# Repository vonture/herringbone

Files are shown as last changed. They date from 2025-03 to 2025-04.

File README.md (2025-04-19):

Herringbone
===============

A split ortholinear grid keyboard made with through hole components.

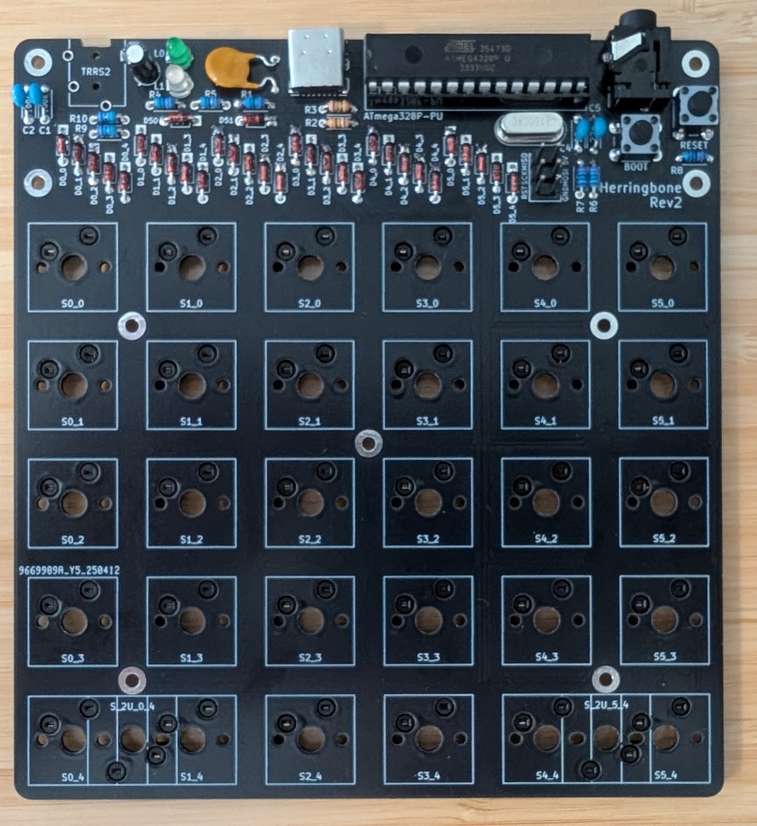
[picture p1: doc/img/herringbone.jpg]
herringbone


## Inspired by
 - [Plaid](https://github.com/hsgw/plaid)
 - [Torn](https://github.com/rtitmuss/torn)
 - [Discipline](https://github.com/coseyfannitutti/discipline)

## BOM

https://octopart.com/bom-tool/v2/9F35A43C-BB16-4669-B263-24A030B88F93

## License



The Herringbone Keyboard is licensed under [Creative Commons Attribution-NonCommercial 4.0 International License](https://creativecommons.org/licenses/by-nc/4.0).

This PCB design may be freely reproduced, modified, and manufactured for personal use only.

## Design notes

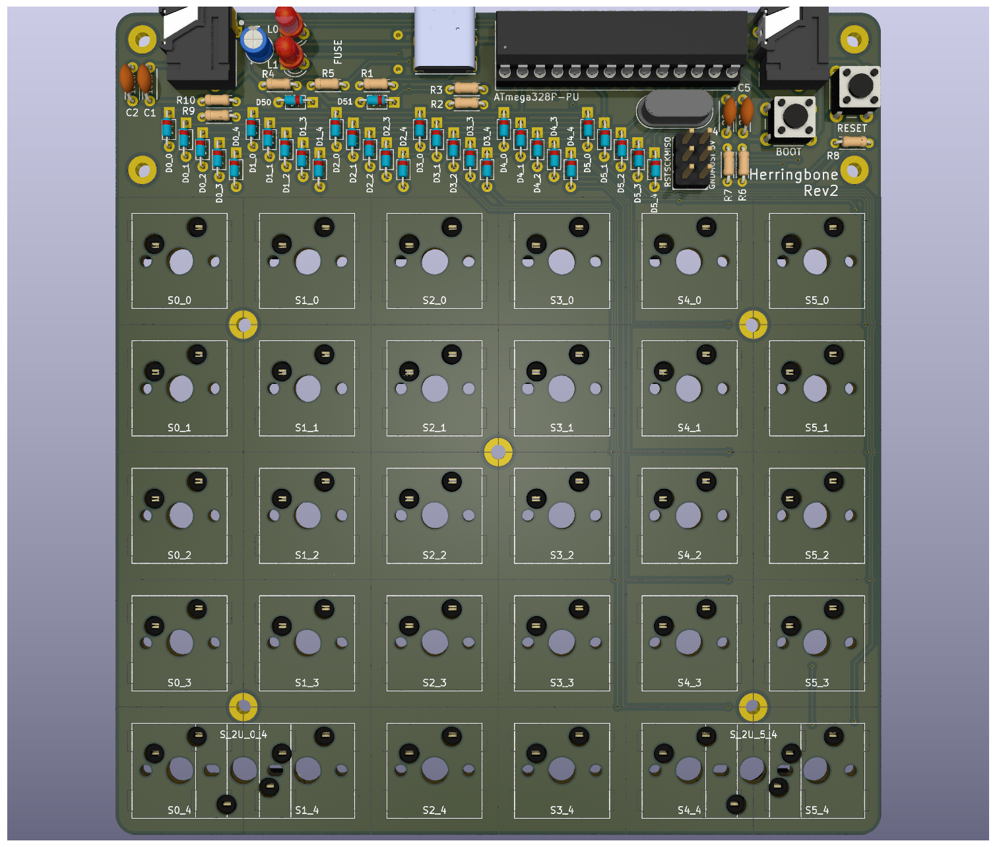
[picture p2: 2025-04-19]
doc/img/pcb.png

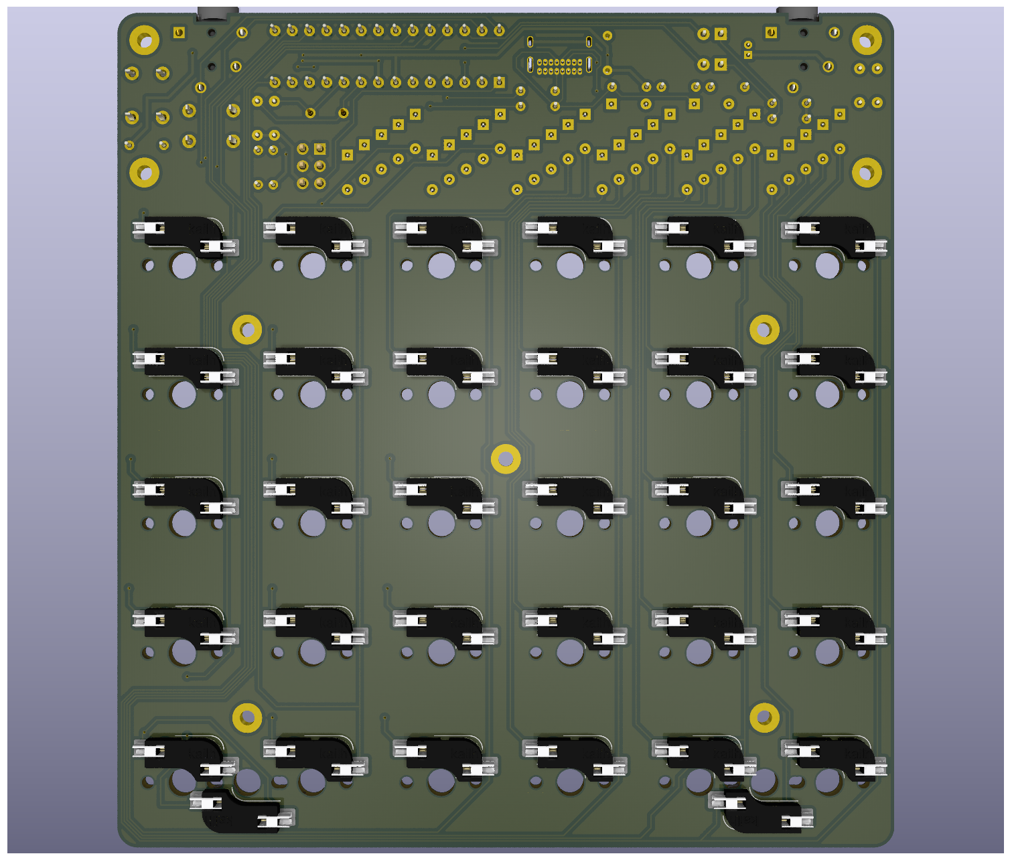
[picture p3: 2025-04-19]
doc/img/pcb_back.png

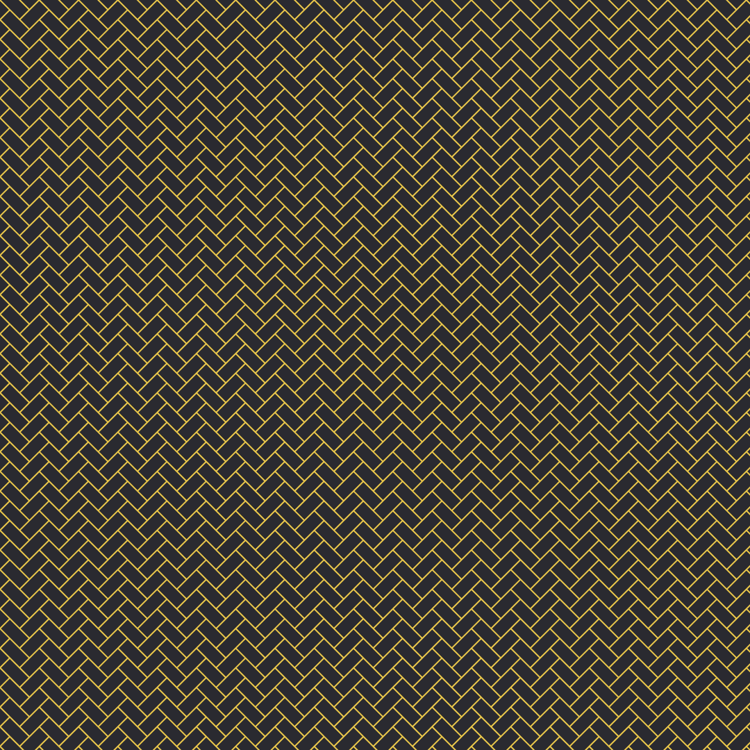
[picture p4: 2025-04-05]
symbols/pattern.png

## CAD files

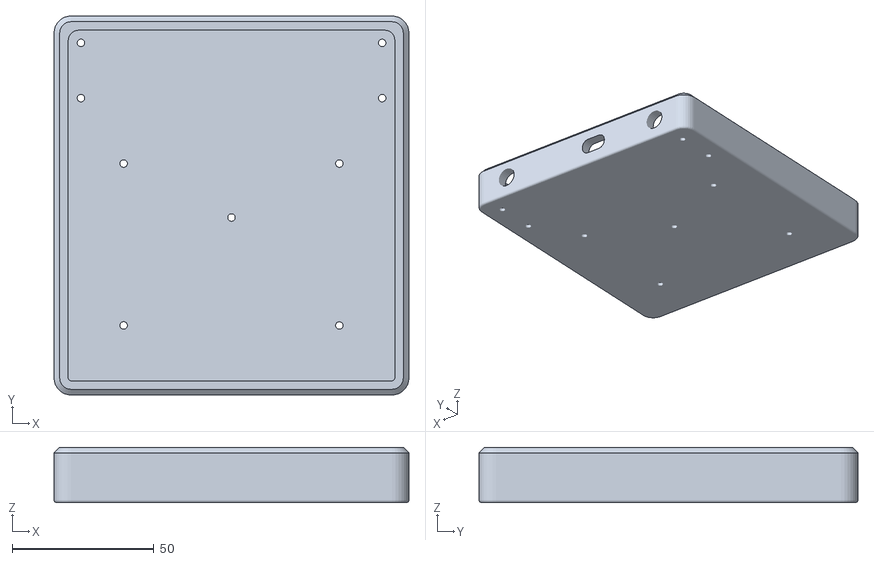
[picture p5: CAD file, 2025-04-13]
case/case/case.stl
125.3 x 133.8 x 19.6

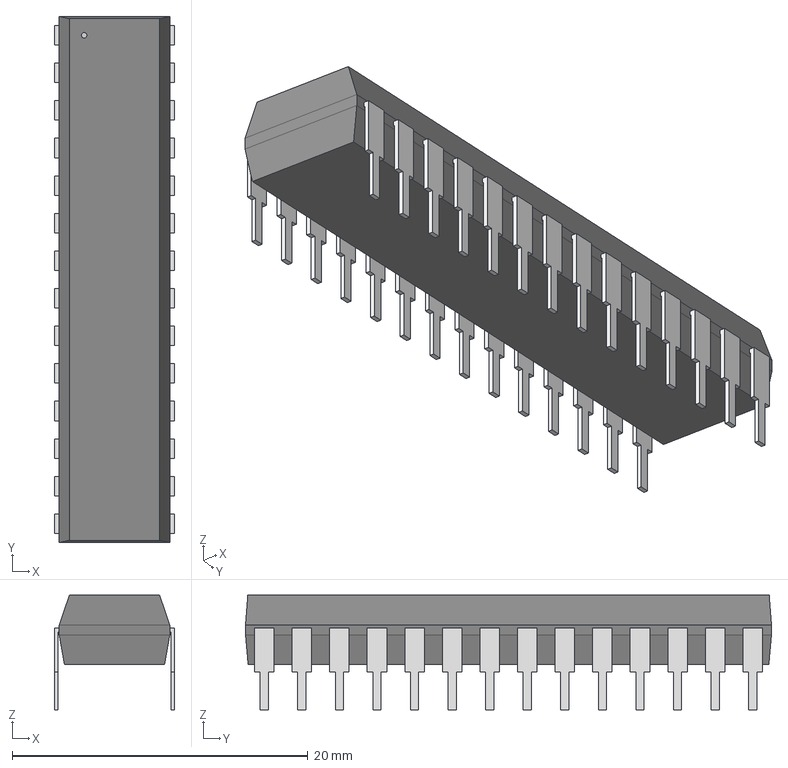
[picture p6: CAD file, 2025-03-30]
models/ATMEGA328_PU/28P3_SPDIP28_SP_MCH.step
8.12 x 35.6 x 7.75 mm

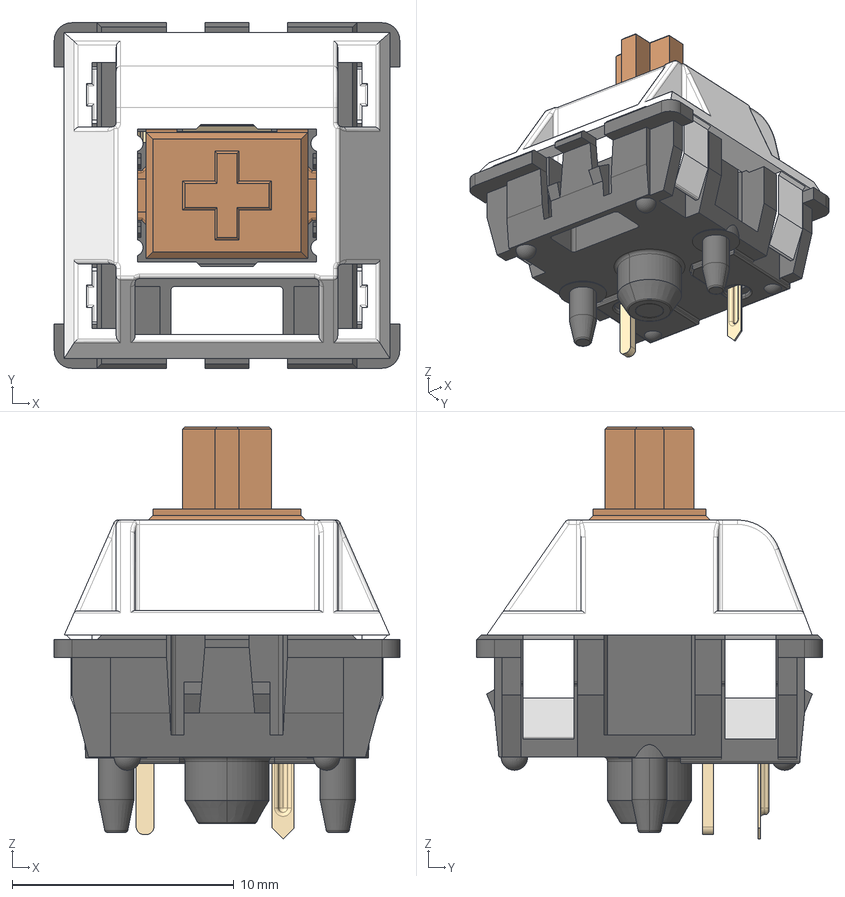
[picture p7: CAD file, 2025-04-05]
models/MX_Switch.step
15.6 x 15.6 x 18.6 mm

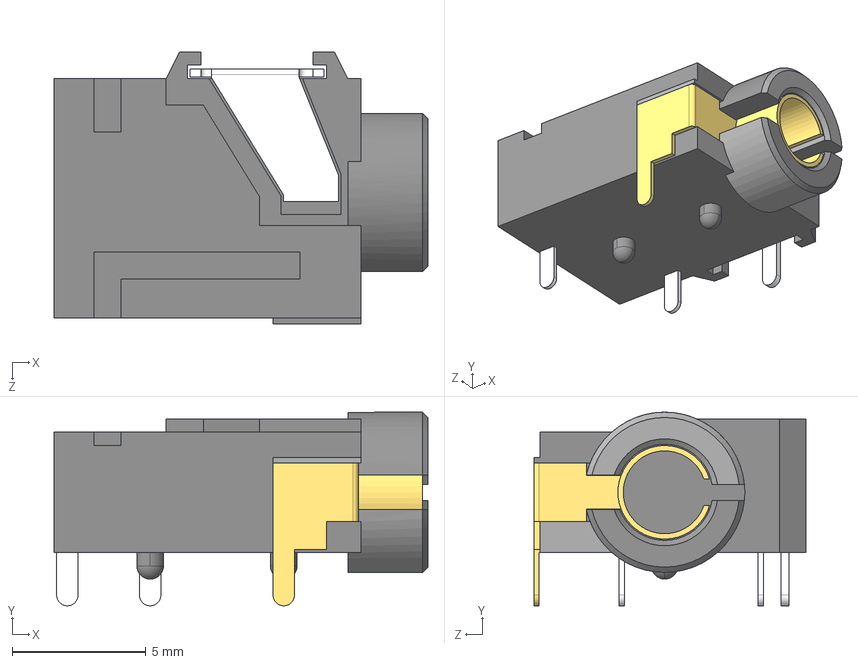
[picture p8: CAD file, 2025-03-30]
models/SJ_43514/SJ-43514.STEP
14.0 x 7.25 x 10.2 mm

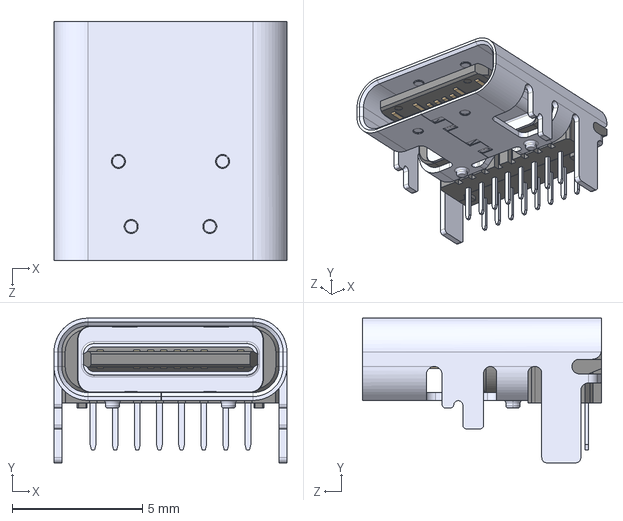
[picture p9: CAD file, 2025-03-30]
models/USB4085_GF_A/USB4085-GF-A.STEP
8.95 x 5.56 x 9.17 mm

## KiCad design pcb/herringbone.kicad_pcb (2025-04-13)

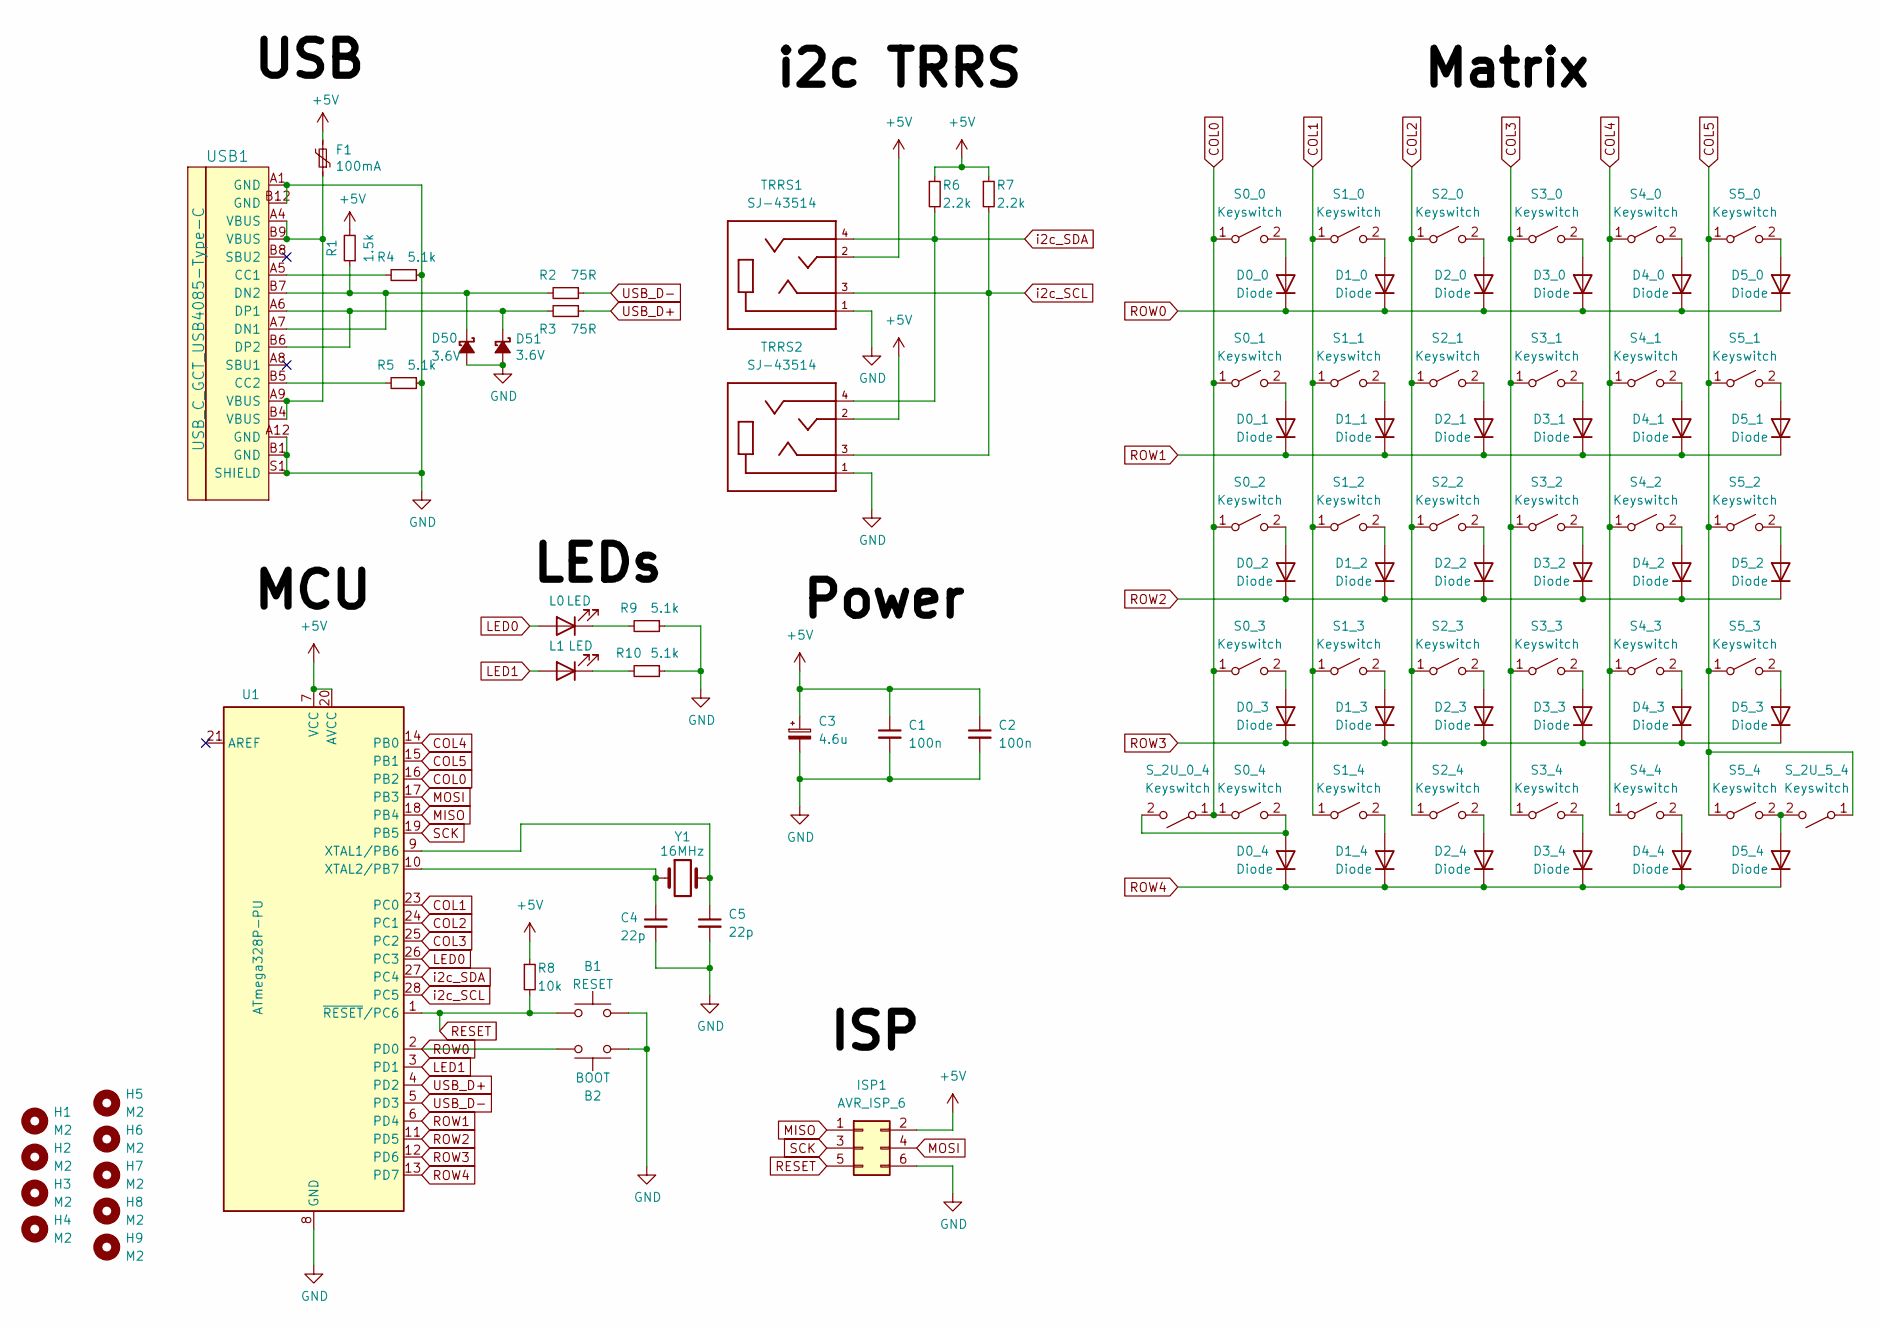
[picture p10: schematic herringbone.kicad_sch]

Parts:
B1: RESET; SW_PUSH_6mm
B2: BOOT; SW_PUSH_6mm
C1, C2: 100n; C_Disc_D4.3mm_W1.9mm_P5.00mm
C3: 4.6u; CP_Radial_D4.0mm_P1.50mm
C4, C5: 22p; C_Disc_D4.3mm_W1.9mm_P5.00mm
D0_0, D0_1, D0_2, D0_3, D0_4, D1_0, D1_1, D1_2, D1_3, D1_4, D2_0, D2_1, D2_2, D2_3, D2_4, D3_0, D3_1, D3_2, D3_3, D3_4, D4_0, D4_1, D4_2, D4_3, D4_4, D5_0, D5_1, D5_2, D5_3, D5_4: Diode; D_DO-35_SOD27_P5.08mm_Horizontal
D50, D51: 3.6V; D_DO-35_SOD27_P5.08mm_Horizontal
F1: 100mA; polyfuse_5.1mm
H1, H2, H3, H4, H5, H6, H7, H8, H9: M2; MountingHole_2.2mm_M2_Pad
ISP1: AVR_ISP_6; AVR_ICSP_3x2
L0, L1: LED; LED_D3.0mm
R1: 1.5k; R_Axial_DIN0204_L3.6mm_D1.6mm_P5.08mm_Horizontal
R2, R3: 75R; R_Axial_DIN0204_L3.6mm_D1.6mm_P5.08mm_Horizontal
R4, R5, R9, R10: 5.1k; R_Axial_DIN0204_L3.6mm_D1.6mm_P5.08mm_Horizontal
R6, R7: 2.2k; R_Axial_DIN0204_L3.6mm_D1.6mm_P5.08mm_Horizontal
R8: 10k; R_Axial_DIN0204_L3.6mm_D1.6mm_P5.08mm_Horizontal
S0_0, S0_1, S0_2, S0_3, S0_4, S1_0, S1_1, S1_2, S1_3, S1_4, S2_0, S2_1, S2_2, S2_3, S2_4, S3_0, S3_1, S3_2, S3_3, S3_4, S4_0, S4_1, S4_2, S4_3, S4_4, S5_0, S5_1, S5_2, S5_3, S5_4: Keyswitch; SW_Hotswap_Kailh_MX_1.00u
S_2U_0_4, S_2U_5_4: Keyswitch; SW_Hotswap_Kailh_MX_2.00u
TRRS1, TRRS2: SJ-43514; CUI_SJ-43514
U1: ATmega328P-PU; ATMEGA328-PU_DIP-28_W7.62mm_Socket
USB1: USB_C_GCT_USB4085-Type-C; USB_C_GCT_USB4085
Y1: 16MHz; Crystal_HC49-4H_Vertical

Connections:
+5V: C1.1, C2.1, C3.1, F1.2, ISP1.2, R1.2, R6.1, R7.1, R8.1, TRRS1.2, TRRS2.2, U1.7 (VCC), U1.20 (AVCC)
COL0: S0_0.1 (A), S0_1.1 (A), S0_2.1 (A), S0_3.1 (A), S0_4.1 (A), S_2U_0_4.1 (A), U1.16 (PB2)
COL1: S1_0.1 (A), S1_1.1 (A), S1_2.1 (A), S1_3.1 (A), S1_4.1 (A), U1.23 (PC0)
COL2: S2_0.1 (A), S2_1.1 (A), S2_2.1 (A), S2_3.1 (A), S2_4.1 (A), U1.24 (PC1)
COL3: S3_0.1 (A), S3_1.1 (A), S3_2.1 (A), S3_3.1 (A), S3_4.1 (A), U1.25 (PC2)
COL4: S4_0.1 (A), S4_1.1 (A), S4_2.1 (A), S4_3.1 (A), S4_4.1 (A), U1.14 (PB0)
COL5: S5_0.1 (A), S5_1.1 (A), S5_2.1 (A), S5_3.1 (A), S5_4.1 (A), S_2U_5_4.1 (A), U1.15 (PB1)
GND: B1.2, B2.1, C1.2, C2.2, C3.2, C4.2, C5.2, D50.2 (A), D51.2 (A), ISP1.6, R4.1, R5.1, R9.1, R10.1, TRRS1.1, TRRS2.1, U1.8 (GND), U1.22 (GND), USB1.A1 (GND), USB1.A12 (GND), USB1.B1 (GND), USB1.B12 (GND), USB1.S1 (SHIELD)
LED0: L0.2 (A), U1.26 (PC3)
LED1: L1.2 (A), U1.3 (PD1)
MISO: ISP1.1, U1.18 (PB4)
MOSI: ISP1.4, U1.17 (PB3)
unnamed: D0_0.2 (A), S0_0.2 (B)
unnamed: D0_1.2 (A), S0_1.2 (B)
unnamed: D0_2.2 (A), S0_2.2 (B)
unnamed: D0_3.2 (A), S0_3.2 (B)
unnamed: D0_4.2 (A), S0_4.2 (B), S_2U_0_4.2 (B)
unnamed: D1_0.2 (A), S1_0.2 (B)
unnamed: D1_1.2 (A), S1_1.2 (B)
unnamed: D1_2.2 (A), S1_2.2 (B)
unnamed: D1_3.2 (A), S1_3.2 (B)
unnamed: D1_4.2 (A), S1_4.2 (B)
unnamed: D2_0.2 (A), S2_0.2 (B)
unnamed: D2_1.2 (A), S2_1.2 (B)
unnamed: D2_2.2 (A), S2_2.2 (B)
unnamed: D2_3.2 (A), S2_3.2 (B)
unnamed: D2_4.2 (A), S2_4.2 (B)
unnamed: D3_0.2 (A), S3_0.2 (B)
unnamed: D3_1.2 (A), S3_1.2 (B)
unnamed: D3_2.2 (A), S3_2.2 (B)
unnamed: D3_3.2 (A), S3_3.2 (B)
unnamed: D3_4.2 (A), S3_4.2 (B)
unnamed: D4_0.2 (A), S4_0.2 (B)
unnamed: D4_1.2 (A), S4_1.2 (B)
unnamed: D4_2.2 (A), S4_2.2 (B)
unnamed: D4_3.2 (A), S4_3.2 (B)
unnamed: D4_4.2 (A), S4_4.2 (B)
unnamed: D5_0.2 (A), S5_0.2 (B)
unnamed: D5_1.2 (A), S5_1.2 (B)
unnamed: D5_2.2 (A), S5_2.2 (B)
unnamed: D5_3.2 (A), S5_3.2 (B)
unnamed: D5_4.2 (A), S5_4.2 (B), S_2U_5_4.2 (B)
unnamed: D50.1 (K), R1.1, R2.2, USB1.A7 (DN1), USB1.B7 (DN2)
unnamed: D51.1 (K), R3.2, USB1.A6 (DP1), USB1.B6 (DP2)
unnamed: F1.1, USB1.A4 (VBUS), USB1.A9 (VBUS), USB1.B4 (VBUS), USB1.B9 (VBUS)
unnamed: L0.1 (K), R9.2
unnamed: L1.1 (K), R10.2
unnamed: C5.1, U1.9 (XTAL1/PB6), Y1.2
unnamed: C4.1, U1.10 (XTAL2/PB7), Y1.1
unnamed: R4.2, USB1.A5 (CC1)
unnamed: R5.2, USB1.B5 (CC2)
RESET: B1.1, ISP1.5, R8.2, U1.1 (~RESET/PC6)
ROW0: B2.2, D0_0.1 (K), D1_0.1 (K), D2_0.1 (K), D3_0.1 (K), D4_0.1 (K), D5_0.1 (K), U1.2 (PD0)
ROW1: D0_1.1 (K), D1_1.1 (K), D2_1.1 (K), D3_1.1 (K), D4_1.1 (K), D5_1.1 (K), U1.6 (PD4)
ROW2: D0_2.1 (K), D1_2.1 (K), D2_2.1 (K), D3_2.1 (K), D4_2.1 (K), D5_2.1 (K), U1.11 (PD5)
ROW3: D0_3.1 (K), D1_3.1 (K), D2_3.1 (K), D3_3.1 (K), D4_3.1 (K), D5_3.1 (K), U1.12 (PD6)
ROW4: D0_4.1 (K), D1_4.1 (K), D2_4.1 (K), D3_4.1 (K), D4_4.1 (K), D5_4.1 (K), U1.13 (PD7)
SCK: ISP1.3, U1.19 (PB5)
USB_D+: R3.1, U1.4 (PD2)
USB_D-: R2.1, U1.5 (PD3)
i2c_SCL: R7.2, TRRS1.3, TRRS2.3, U1.28 (PC5)
i2c_SDA: R6.2, TRRS1.4, TRRS2.4, U1.27 (PC4)

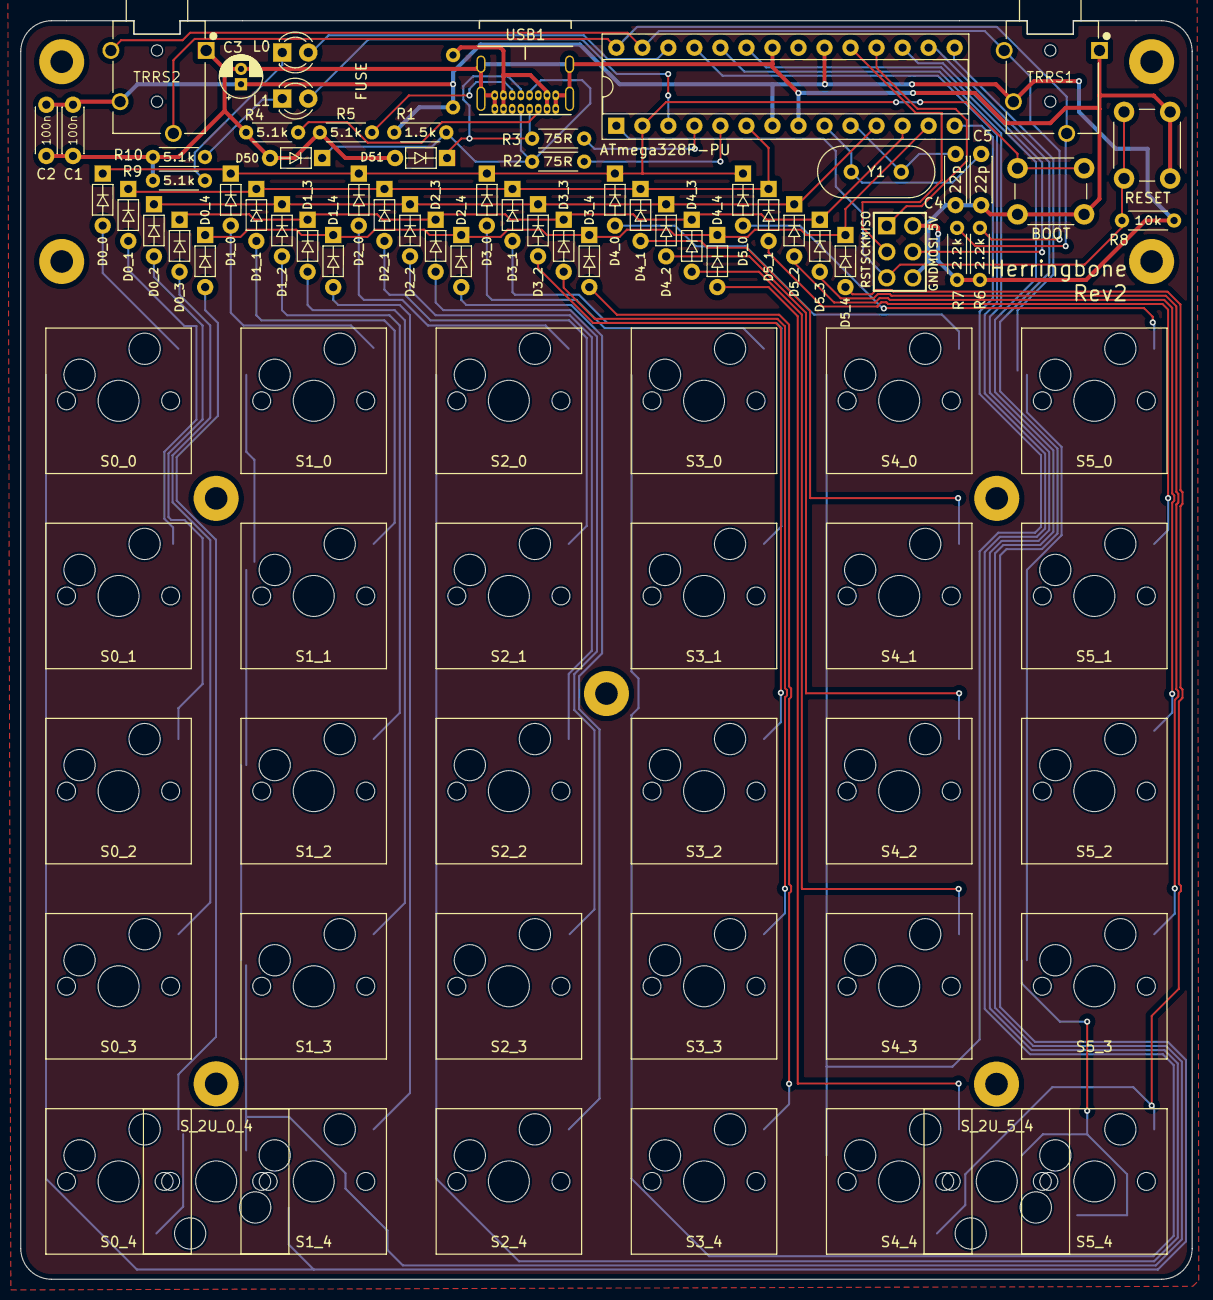
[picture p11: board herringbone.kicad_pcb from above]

Board: 2 copper layers, 114.3 x 122.8 mm, 99 parts (0 on the bottom side), 62 nets.

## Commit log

2025-03-29 Initial schematics and pcb design.
    [herringbone.kicad_pcb, herringbone.kicad_sch]
2025-03-29 Second TRRS jack
    [herringbone.kicad_pcb, herringbone.kicad_sch]
2025-03-29 Rebuild zones.
    [herringbone.kicad_pcb]
2025-03-30 Add new footprints and add models.
    [28P3_SPDIP28_SP_MCH.step, SJ-43514.STEP, USB4085-GF-A.STEP]
2025-03-30 Add plate and bottom.
    [bottom.kicad_pcb, herringbone.kicad_pcb, herringbone.kicad_sch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]
2025-03-31 Acrylic top and bottom.
    [acrylic.kicad_pcb, bottom.kicad_pcb]
2025-04-05 Add acrylic cutouts.
    [acrylic.dxf, bottom.dxf]
2025-04-05 Move kicad projects to subfolders.
    [MX_Switch.step, acrylic.dxf, bottom.dxf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]
2025-04-12 PCB rev2.
    - Add LEDs
    - Fix D+ D- USB pins for USBaspLoader to be happy
    - Widen power Lines
    - Allow for 2U keys in bottom corners
    [herringbone.kicad_pcb, herringbone.kicad_sch, plate.kicad_pcb]
2025-04-12 Add BOM
2025-04-12 Update image of rev2 pcb.
2025-04-13 Add case models.
    [case.stl]
2025-04-13 pcb and footprint updates.
    [herringbone.kicad_pcb]
2025-04-19 Add image of soldered board.
